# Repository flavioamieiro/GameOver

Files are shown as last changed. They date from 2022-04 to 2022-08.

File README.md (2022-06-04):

Hardware for Game Over project

[BaseBoard](BaseBoard/) contains the design files for the  main board, which
has an ESP32 and will be the base for the add-ons.

[BNO055Sensor](BNO055Sensor/) is the first add-on: basically a BNO055 sensor
from Adafruit used for motion detection.

[Keypad](Keypad/) is a keypad with six buttons and LEDs to be used as
an interface.

[BreakoutBoard](BreakoutBoard/) is a simple breakout board for easier
prototyping using the base board.

[AddonTemplate](AddonTemplate/) is a kicad template you can use as a base to
create new addon boards.

This source describes Open Hardware and is licensed under the CERN-OHL-S v2.
You may redistribute and modify this source and make products using it under
the terms of the [CERN-OHL-S v2](https://ohwr.org/cern_ohl_s_v2.txt).

Source location: https://github.com/flavioamieiro/GameOver

As per CERN-OHL-S v2 section 4, should You produce hardware based on this
source, You must where practicable maintain the Source Location visible on the
external case of the Gizmo or other products you make using this source.

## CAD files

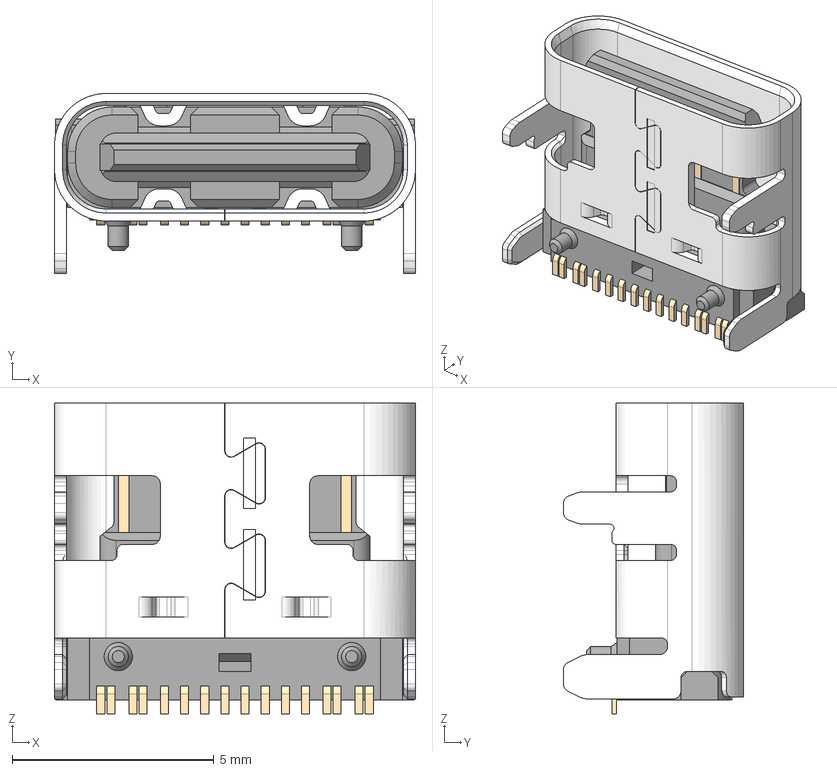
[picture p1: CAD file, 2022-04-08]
BNO055Sensor/3D-models/USB_C_Receptacle_USB_2_GTC_USB4105.step
8.94 x 4.46 x 7.70 mm
Move Face1
Imported1

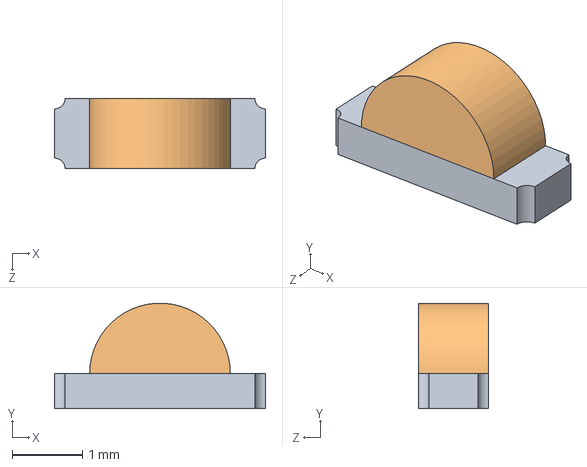
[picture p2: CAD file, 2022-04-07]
BNO055Sensor/3D-models/RGB_LED.step
3.00 x 1.50 x 1.00 mm

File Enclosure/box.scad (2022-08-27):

include <common.scad>

BOX_HAS_LOGO = true;

pcb_spacer_height = 5;
pcb_spacer_diameter = 6;
usb_support_offset = 5;

strap_cutout_size = [20, 100, 1.5];

button_hole_radius = 1;
button_center_height_from_board = 1.7;
button_1_from_left_edge = 18.8;
button_2_from_left_edge = 34.9;
button_3_from_left_edge = 40.5;

led_window_radius = 0.6;
led_window_thickness = 0.4;
led_from_left_edge = 25.3;
led_center_height_from_board = 0.5;

usb_height = 7;
usb_length = 13;
usb_z_padding = 1.5;
usb_center_from_pcb_bottom_edge = 24.65;


module main_box() {
	difference() {
		rounded_box(outer_size, radius=rounded_corner_radius);
		translate(inner_pocket_offset) rounded_box(inner_size, radius=rounded_corner_radius);
	}
}

module support_spacer() {
	inner_h = pcb_spacer_height;
	outer_d = pcb_spacer_diameter;
	outer_h = inner_h + wall_thickness;
	inner_offset_z = (outer_h - inner_h);
	cylinder(outer_h, d=outer_d);
}

module pcb_spacers() {
	translate(left_screw_pos) heat_set_insert_M2();
	translate([left_screw_pos.x+usb_support_offset, right_screw_pos.y, 0]) support_spacer();
	translate([right_screw_pos.x, left_screw_pos.y, 0]) support_spacer();
	translate(right_screw_pos) heat_set_insert_M2();
}

module strap_cutout() {
	translate([(outer_size.x / 2)-(strap_cutout_size.x/2), 0, wall_thickness]) cube(strap_cutout_size);
}

module led_window() {
	x = wall_thickness + wall_to_pcb_spacing + led_from_left_edge;
	y = outer_size.y - led_window_thickness;
	z = pcb_spacer_height + wall_thickness - led_center_height_from_board;
	cylinder_height = wall_thickness - led_window_thickness;
	translate([x, y, z]) rotate(a=90, v=[1, 0, 0]) cylinder(cylinder_height, r=led_window_radius);
}

module button_access(dist_from_left_pcb_edge) {
	x = wall_thickness + wall_to_pcb_spacing + dist_from_left_pcb_edge;
	y = outer_size.y;
	z = pcb_spacer_height + wall_thickness + pcb_size.z + button_center_height_from_board;
	translate([x, y, z]) rotate(a=90, v=[1, 0, 0])  cylinder(wall_thickness, r=button_hole_radius);
}

module button_accesses() {
	button_access(button_1_from_left_edge);
	button_access(button_2_from_left_edge);
	button_access(button_3_from_left_edge);
}

module usb_port_access() {
	radius = usb_height/2;
	center_y = wall_thickness + wall_to_pcb_spacing + usb_center_from_pcb_bottom_edge;
	y = center_y - (usb_length/2);
	z = wall_thickness + pcb_spacer_height - usb_height + usb_z_padding;
	translate([wall_thickness*2, y, z]) rotate(a=270, v=[0, 1, 0]) hull() {
		translate([radius, radius, 0]) cylinder(wall_thickness*2, r=radius);
		translate([radius, usb_length-radius, 0]) cylinder(wall_thickness*2, r=radius);
	}
}

module logo() {
	translate([outer_size.x-(wall_thickness/2), outer_size.y-(inner_size.y-wall_thickness), 0]) rotate([90, 0, 90]) scale([0.1, 0.1, 1]) linear_extrude(height=wall_thickness/2) import("logo.svg");
}

difference() {
	main_box();
	strap_cutout();
	button_accesses();
	led_window();
	usb_port_access();
	if (BOX_HAS_LOGO) {
		logo();
	}
}
pcb_spacers();

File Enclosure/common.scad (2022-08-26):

$fn=100;

rounded_corner_radius = 3;
wall_thickness = 2;
wall_to_pcb_spacing = 1;

inner_width = 50;
inner_depth = 35;
inner_height = 17;

pcb_size = [50, 35, 1.6];

right_side_padding = 15;

screw_center_from_pcb_edge = 3;
ffc_connector_from_right_pcb_edge = 5.5;


// Calculated variables
pcb_to_wall_padding = [1, 1, 1] * (2*wall_to_pcb_spacing);
inner_size = [inner_width + right_side_padding, inner_depth, inner_height] + pcb_to_wall_padding;
inner_pocket_offset = [1, 1, 1] * wall_thickness;

left_screw_pos = [wall_thickness + wall_to_pcb_spacing + screw_center_from_pcb_edge, wall_thickness + wall_to_pcb_spacing + screw_center_from_pcb_edge, 0];

right_screw_pos = [wall_thickness + wall_to_pcb_spacing + pcb_size.x - screw_center_from_pcb_edge, wall_thickness + wall_to_pcb_spacing + pcb_size.y - screw_center_from_pcb_edge, 0];

two_walls = (wall_thickness * 2);
outer_size = inner_size + [two_walls, two_walls, wall_thickness];


// Modules
module rounded_box(size = [1, 1, 1], radius=1) {
	if (size[0] == undef) {
		size = [size, size, size];
	}

	hull() {
		translate([radius, radius, 0]) cylinder(size.z, r=radius);
		translate([size.x-radius, radius, 0]) cylinder(size.z, r=radius);
		translate([radius, size.y-radius, 0]) cylinder(size.z, r=radius);
		translate([size.x-radius, size.y-radius, 0]) cylinder(size.z, r=radius);
	}
}

module heat_set_insert_M2() {
	inner_d = 3.2;
	inner_h = pcb_spacer_height;
	outer_d = pcb_spacer_diameter;
	outer_h = inner_h + wall_thickness;
	inner_offset_z = (outer_h - inner_h);
	difference() {
		cylinder(outer_h, d=outer_d);
		translate([0, 0, inner_offset_z]) cylinder(inner_h, d=inner_d);
	}
}

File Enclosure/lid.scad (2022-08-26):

include <common.scad>

LID_HAS_SCREW = false;
LID_HAS_LOGO = false;


lid_overhang = 5;
vertical_lid_wall_height = 1.5;
vertical_lid_wall_thickness = 1;

lid_outer_size = [outer_size.x, outer_size.y, wall_thickness*2];



module screw_hole() {
	inner_d = 3.2;
	inner_h = lid_outer_size.z;
	outer_d = 4.5;
	outer_h = inner_h/2;
	cylinder(inner_h, d=inner_d);
	translate([0, 0, outer_h]) cylinder(outer_h, d=outer_d);
}


module main_body() {
	opening_right_backoff = ((wall_to_pcb_spacing+wall_thickness)*2) + right_side_padding + ffc_connector_from_right_pcb_edge;
	opening_size = inner_size - [opening_right_backoff, lid_overhang, -100];
	translate([0, 0, vertical_lid_wall_height]) union() {
		difference() {
			rounded_box(lid_outer_size, radius=rounded_corner_radius);
			translate([lid_overhang, lid_overhang, 0]) rounded_box(opening_size, radius=rounded_corner_radius);
		};
	};
}


module vertical_walls() {
	out_size = lid_outer_size - [2*wall_thickness, 2*wall_thickness, -vertical_lid_wall_height];
	in_size = out_size - [2*vertical_lid_wall_thickness, 2*vertical_lid_wall_thickness, 0];
	translate([wall_thickness, wall_thickness, 0]) {
		difference() {
			rounded_box(out_size, radius=rounded_corner_radius);
			translate([vertical_lid_wall_thickness, vertical_lid_wall_thickness, 0]) rounded_box(in_size, radius=rounded_corner_radius);
		}
	}
}


module screw_opening() {
	z = vertical_lid_wall_height;
	translate([right_screw_pos.x, right_screw_pos.y, z]) screw_hole();
}


module logo() {
	translate([lid_outer_size.x, lid_outer_size.y-inner_size.y, lid_outer_size.z]) rotate([0, 0, 90]) scale([0.1, 0.1, 1]) linear_extrude(height=lid_outer_size.z/2) import("logo.svg");
}


difference() {
	union() {
		main_body();
		vertical_walls();
	}
	if (LID_HAS_SCREW) {
		screw_opening();
	}
	if (LID_HAS_LOGO) {
		logo();
	}
}

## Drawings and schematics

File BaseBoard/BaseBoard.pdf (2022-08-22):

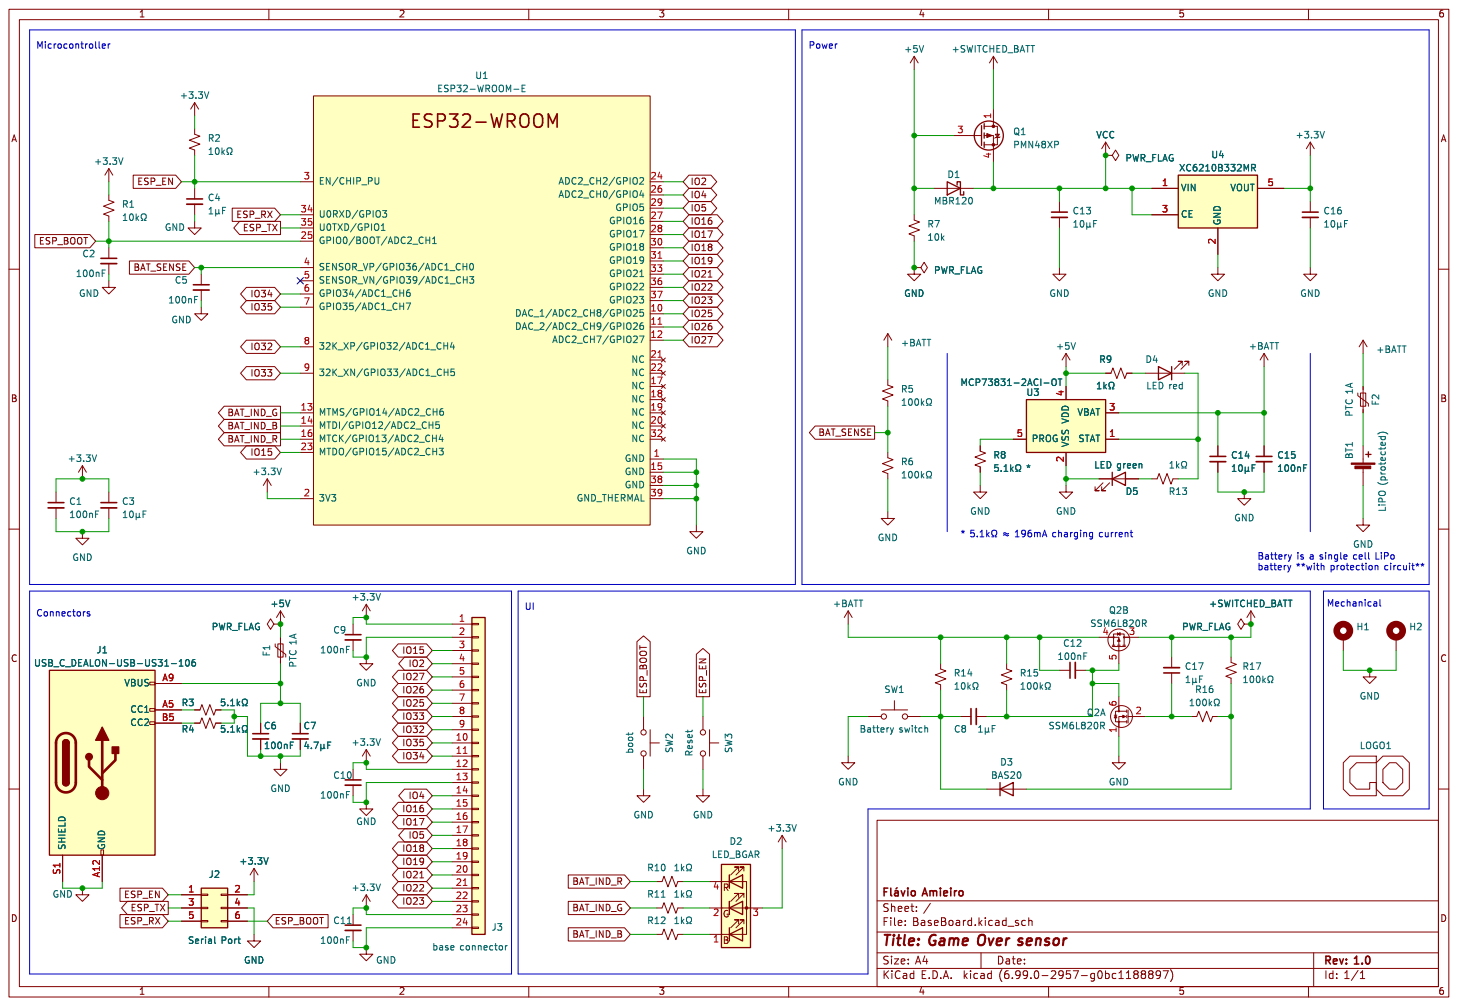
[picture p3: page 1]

þÿ10µF GND GND GND

battery **with protection circuit** Connectors

File: BaseBoard.kicad_sch Sheet: / þÿFlávio Amieiro C7

Id: 1/1 Title: Game Over sensor

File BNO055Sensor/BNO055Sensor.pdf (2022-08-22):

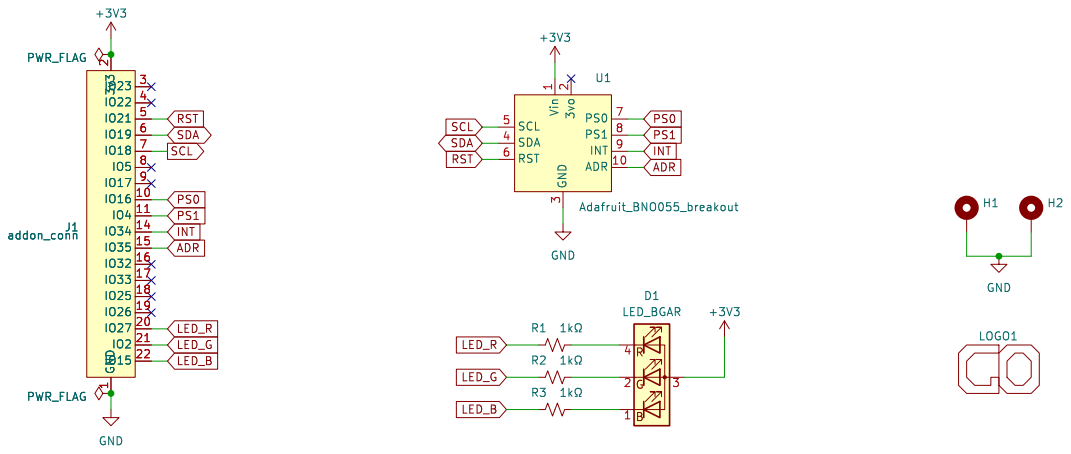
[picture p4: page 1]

Id: 1/1 Title: Game Over Sensor addon

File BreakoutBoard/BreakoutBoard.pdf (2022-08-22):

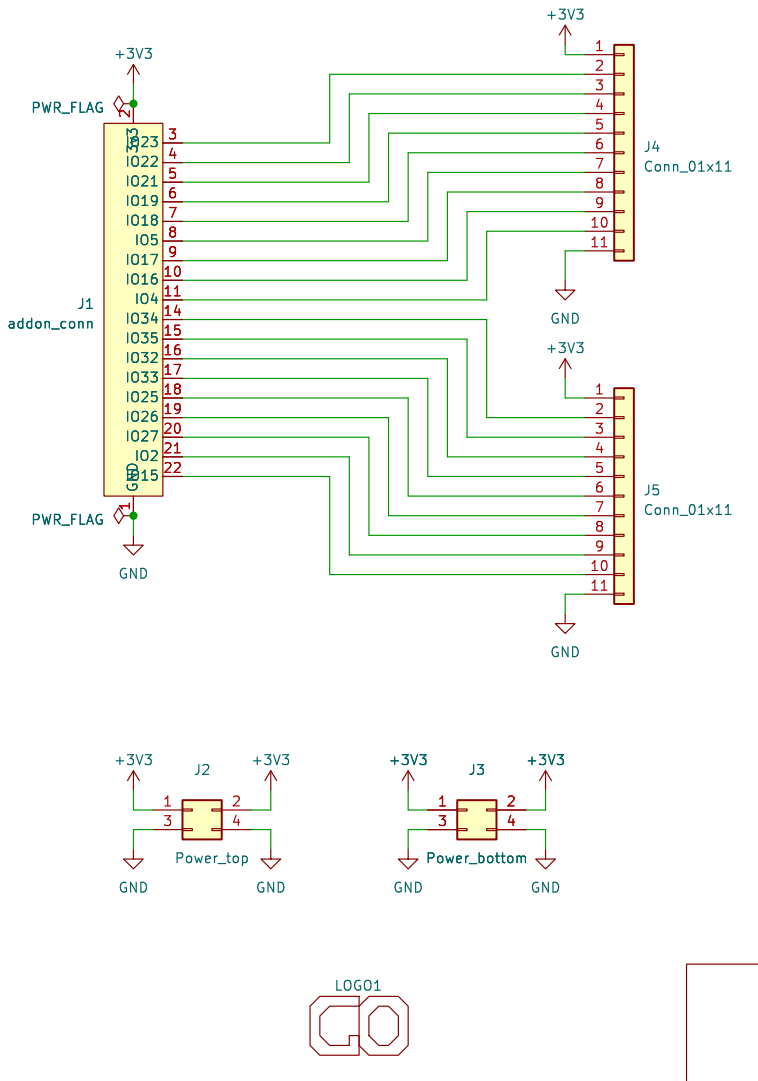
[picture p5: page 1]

Id: 1/1 Title: GameOver breakout board

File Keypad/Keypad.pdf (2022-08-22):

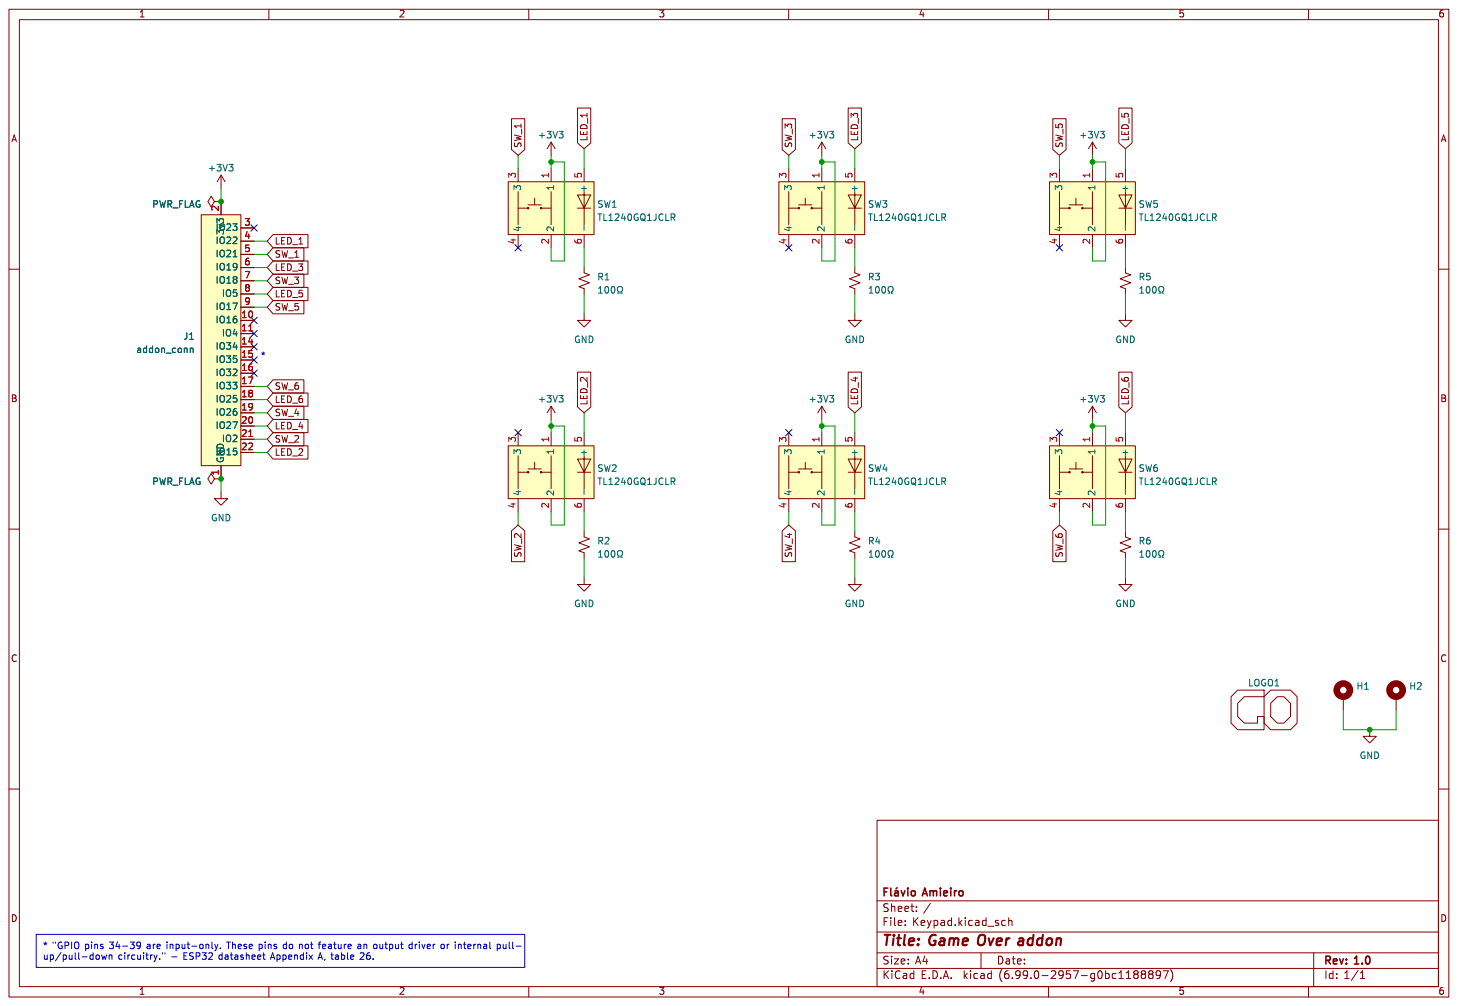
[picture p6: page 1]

Id: 1/1 Title: Game Over addon

* "GPIO pins 34-39 are input-only. These pins do not feature an output driver or internal pull-
up/pull-down circuitry." - ESP32 datasheet Appendix A, table 26.

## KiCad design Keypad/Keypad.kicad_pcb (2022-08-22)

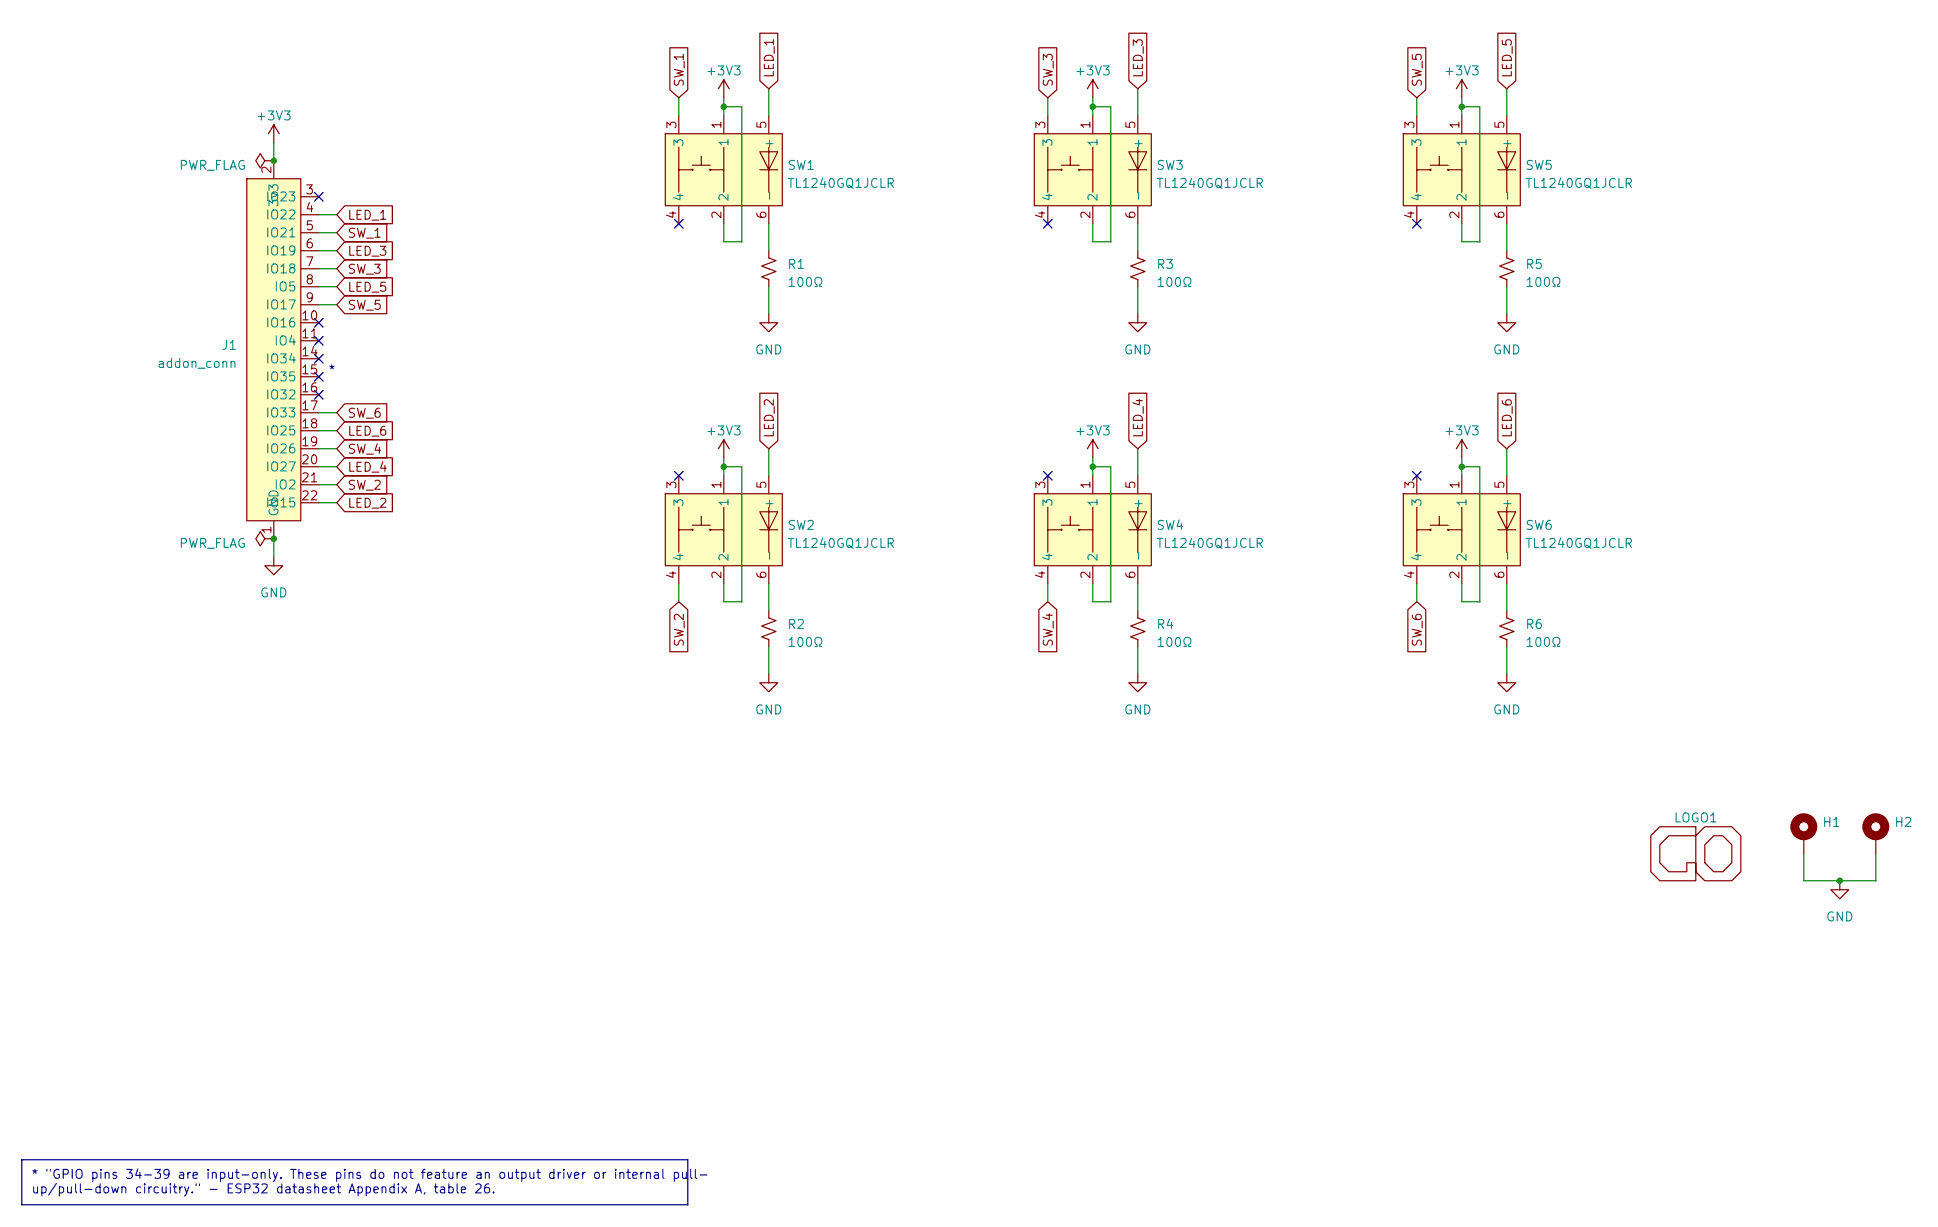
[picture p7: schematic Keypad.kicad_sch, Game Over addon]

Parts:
H1, H2: MountingHole_2.2mm_M2_Pad_Via
J1: addon_conn; Addon_conn_TXGA_FFC05036-24SBD113W5M_1x24_P0.50mm_Horizontal
LOGO1: GameOver_logo; logo_fcu
R1, R2, R3, R4, R5, R6: 100Ω; R_0805_2012Metric_Pad1.20x1.40mm_HandSolder
SW1, SW2, SW3, SW4, SW5, SW6: TL1240GQ1JCLR

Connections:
+3V3: J1.2 (3v3), J1.13 (3v3), J1.24 (3v3), SW1.1, SW1.2, SW2.1, SW2.2, SW3.1, SW3.2, SW4.1, SW4.2, SW5.1, SW5.2, SW6.1, SW6.2
GND: H1.1, H2.1, J1.1 (GND), J1.12 (GND), J1.23 (GND), R1.2, R2.2, R3.2, R4.2, R5.2, R6.2
LED_1: J1.4 (IO22), SW1.5 (+)
LED_2: J1.22 (IO15), SW2.5 (+)
LED_3: J1.6 (IO19), SW3.5 (+)
LED_4: J1.20 (IO27), SW4.5 (+)
LED_5: J1.8 (IO18), SW5.5 (+)
LED_6: J1.18 (IO25), SW6.5 (+)
unnamed: R1.1, SW1.6 (-)
unnamed: R2.1, SW2.6 (-)
unnamed: R3.1, SW3.6 (-)
unnamed: R4.1, SW4.6 (-)
unnamed: R5.1, SW5.6 (-)
unnamed: R6.1, SW6.6 (-)
SW_1: J1.5 (IO21), SW1.3
SW_2: J1.21 (IO2), SW2.4
SW_3: J1.7 (IO5), SW3.3
SW_4: J1.19 (IO26), SW4.4
SW_5: J1.9 (IO17), SW5.3
SW_6: J1.17 (IO33), SW6.4

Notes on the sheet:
* "GPIO pins 34-39 are input-only. These pins do not feature an output driver or internal pull- up/pull-down circuitry." - ESP32 datasheet Appendix A, table 26.

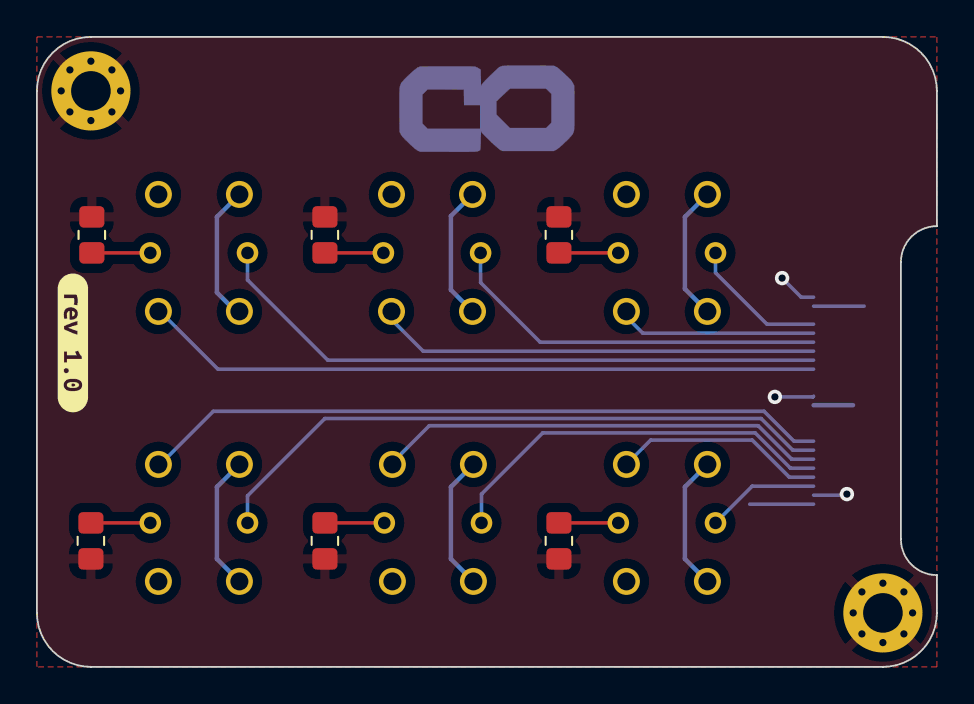
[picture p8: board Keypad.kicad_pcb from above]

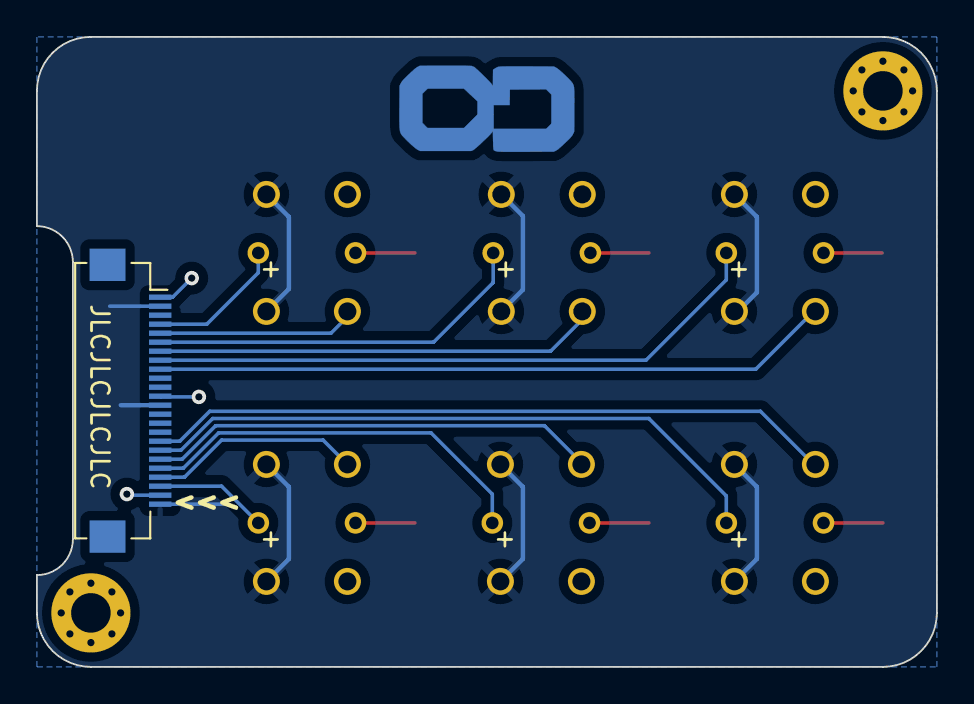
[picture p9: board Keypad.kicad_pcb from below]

Board: 2 copper layers, 50.0 x 35.0 mm, 17 parts (8 on the bottom side), 20 nets.

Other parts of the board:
kibuzzard-63029D1F: G***; kibuzzard-63029D1F

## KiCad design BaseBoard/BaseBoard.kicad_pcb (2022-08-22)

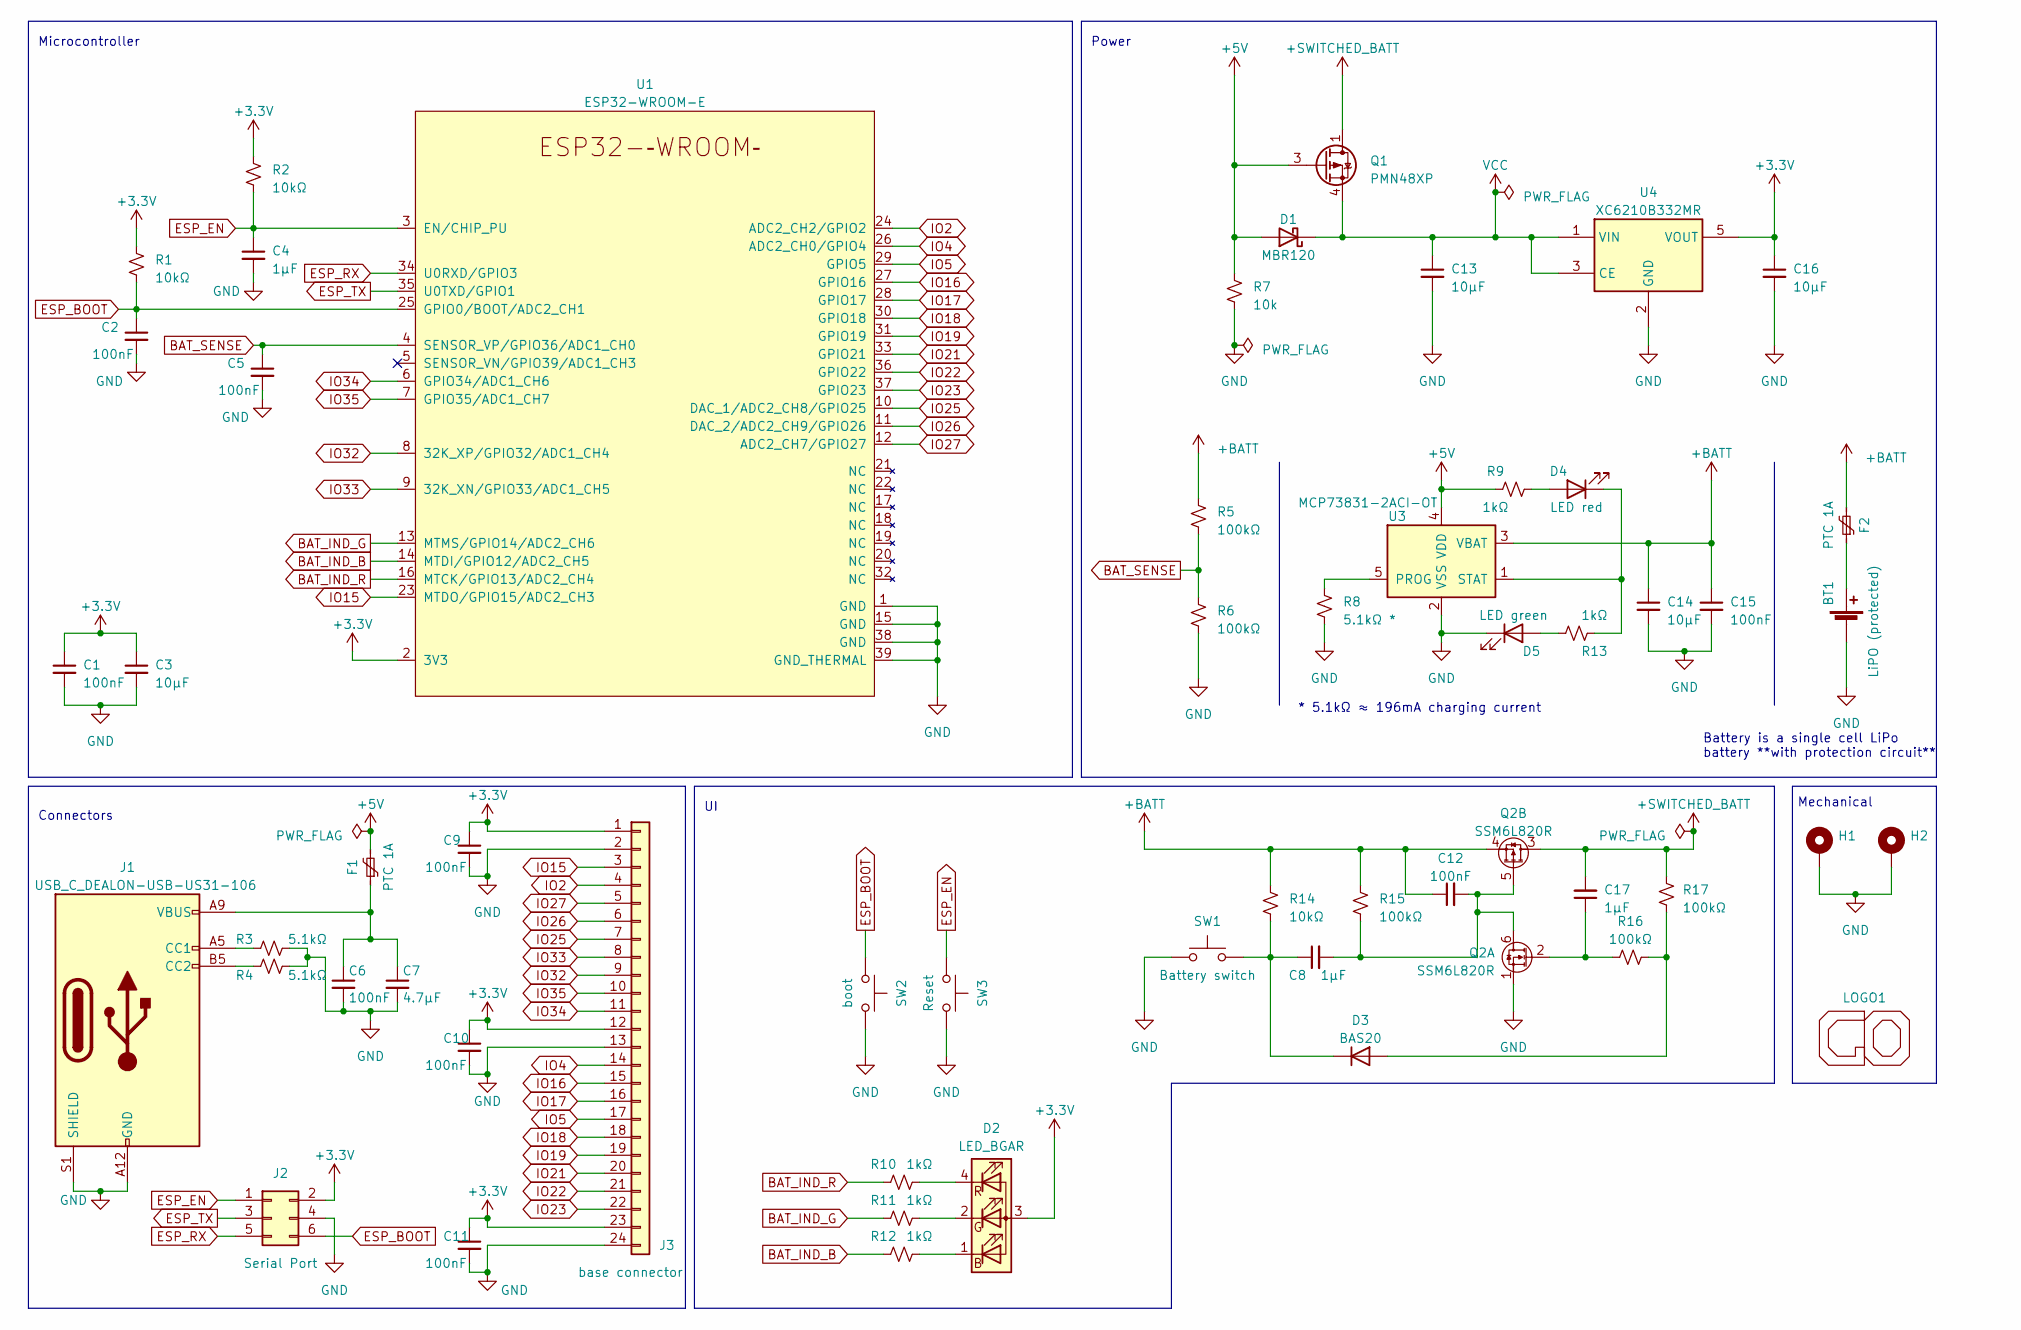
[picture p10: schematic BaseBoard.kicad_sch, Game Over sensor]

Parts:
BT1: LiPO (protected); JST_PH_S2B-PH-SM4-TB_1x02-1MP_P2.00mm_Horizontal
C1, C2, C5, C6, C9, C10, C11, C12, C15: 100nF; C_0805_2012Metric_Pad1.18x1.45mm_HandSolder
C3, C13, C14, C16: 10µF; C_0805_2012Metric_Pad1.18x1.45mm_HandSolder
C4, C8, C17: 1µF; C_0805_2012Metric_Pad1.18x1.45mm_HandSolder
C7: 4.7µF; C_0805_2012Metric_Pad1.18x1.45mm_HandSolder
D1: MBR120; D_SOD-123
D2: LED_BGAR; Hongzhi_Forest_HS-1204-RGB
D3: BAS20; SOT-23
D4: LED red; LED_0603_1608Metric
D5: LED green; LED_0603_1608Metric
F1, F2: PTC 1A; Belfuse_0ZCJ
H1, H2: MountingHole_2.2mm_M2_Pad_Via
J1: USB_C_DEALON-USB-US31-106; DEALON_USB-US31-106
J2: Serial Port; Tag-Connect_TC2030-IDC-FP_2x03_P1.27mm_Vertical
J3: base connector; Base_conn_TXGA_FFC05036-24SBD113W5M_1x24_P0.50mm_Horizontal
LOGO1: GameOver_logo; logo_fsilk
Q1: PMN48XP; TSOP-6_1.65x3.05mm_P0.95mm
Q2: SSM6L820R; TSOP6F
R1, R2, R14: 10kΩ; R_0805_2012Metric_Pad1.20x1.40mm_HandSolder
R3, R4: 5.1kΩ; R_0805_2012Metric_Pad1.20x1.40mm_HandSolder
R5, R6, R15, R16, R17: 100kΩ; R_0805_2012Metric_Pad1.20x1.40mm_HandSolder
R7: 10k; R_0805_2012Metric_Pad1.20x1.40mm_HandSolder
R8: 5.1kΩ *; R_0805_2012Metric_Pad1.20x1.40mm_HandSolder
R9, R10, R11, R12, R13: 1kΩ; R_0805_2012Metric_Pad1.20x1.40mm_HandSolder
SW1: Battery switch; SW_Tactile_SPST_SOFNG_TS-1814
SW2: boot; SW_Tactile_SPST_SOFNG_TS-1814
SW3: Reset; SW_Tactile_SPST_SOFNG_TS-1814
U1: ESP32-WROOM-E; ESP32-WROOM-32E
U3: MCP73831-2ACI-OT; SOT-23-5
U4: XC6210B332MR; SOT-23-5

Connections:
+3V3: C1.1, C3.1, C9.1, C10.1, C11.1, C16.1, D2.3 (A), J2.2, J3.1, J3.12, J3.23, R1.1, R2.1, U1.2 (3V3), U4.5 (VOUT)
+5V: D1.2 (A), F1.2, Q1.3 (G), R7.1, R9.2, U3.4 (VDD)
+BATT: C12.1, C14.1, C15.1, F2.2, Q2.4 (S), R5.1, R14.1, R15.1, U3.3 (VBAT)
+SWITCHED_BATT: C17.2, Q1.1 (D), Q1.2 (D), Q1.5 (D), Q1.6 (D), Q2.3 (D), R17.2
BAT_IND_B: R12.1, U1.14 (MTDI/GPIO12/ADC2_CH5)
BAT_IND_G: R11.1, U1.13 (MTMS/GPIO14/ADC2_CH6)
BAT_IND_R: R10.1, U1.16 (MTCK/GPIO13/ADC2_CH4)
BAT_SENSE: C5.1, R5.2, R6.1, U1.4 (SENSOR_VP/GPIO36/ADC1_CH0)
ESP_BOOT: C2.1, J2.6, R1.2, SW2.1, U1.25 (GPIO0/BOOT/ADC2_CH1)
ESP_EN: C4.1, J2.1, R2.2, SW3.1, U1.3 (EN/CHIP_PU)
ESP_RX: J2.5, U1.34 (U0RXD/GPIO3)
ESP_TX: J2.3, U1.35 (U0TXD/GPIO1)
GND: BT1.2 (-), C1.2, C2.2, C3.2, C4.2, C5.2, C6.2, C7.2, C9.2, C10.2, C11.2, C13.2, C14.2, C15.2, C16.2, D5.1 (K), H1.1, H2.1, J1.A12 (GND), J1.B12 (GND), J1.S1 (SHIELD), J2.4, J3.2, J3.13, J3.24, Q2.1 (S), R3.2, R4.2, R6.2, R7.2, R8.2, SW1.1, SW2.2, SW3.2, U1.1 (GND), U1.15 (GND), U1.38 (GND), U1.39 (GND_THERMAL), U3.2 (VSS), U4.2 (GND)
IO2: J3.4, U1.24 (ADC2_CH2/GPIO2)
IO4: J3.14, U1.26 (ADC2_CH0/GPIO4)
IO5: J3.17, U1.29 (GPIO5)
IO15: J3.3, U1.23 (MTDO/GPIO15/ADC2_CH3)
IO16: J3.15, U1.27 (GPIO16)
IO17: J3.16, U1.28 (GPIO17)
IO18: J3.18, U1.30 (GPIO18)
IO19: J3.19, U1.31 (GPIO19)
IO21: J3.20, U1.33 (GPIO21)
IO22: J3.21, U1.36 (GPIO22)
IO23: J3.22, U1.37 (GPIO23)
IO25: J3.7, U1.10 (DAC_1/ADC2_CH8/GPIO25)
IO26: J3.6, U1.11 (DAC_2/ADC2_CH9/GPIO26)
IO27: J3.5, U1.12 (ADC2_CH7/GPIO27)
IO32: J3.9, U1.8 (32K_XP/GPIO32/ADC1_CH4)
IO33: J3.8, U1.9 (32K_XN/GPIO33/ADC1_CH5)
IO34: J3.11, U1.6 (GPIO34/ADC1_CH6)
IO35: J3.10, U1.7 (GPIO35/ADC1_CH7)
unnamed: BT1.1 (+), F2.1
unnamed: D2.1 (BK), R12.2
unnamed: D2.2 (GK), R11.2
unnamed: D2.4 (RK), R10.2
unnamed: D3.1 (A), R16.2, R17.1
unnamed: C8.1, D3.3 (K), R14.2, SW1.2
unnamed: D4.2 (A), R9.1
unnamed: D4.1 (K), R13.2, U3.1 (STAT)
unnamed: D5.2 (A), R13.1
unnamed: J1.A5 (CC1), R3.1
unnamed: J1.B5 (CC2), R4.1
unnamed: C6.1, C7.1, F1.1, J1.A9 (VBUS), J1.B9 (VBUS)
unnamed: C8.2, C12.2, Q2.5 (G), Q2.6 (D), R15.2
unnamed: C17.1, Q2.2 (G), R16.1
unnamed: R8.1, U3.5 (PROG)
VCC: C13.1, D1.1 (K), Q1.4 (S), U4.1 (VIN), U4.3 (CE)

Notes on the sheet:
Microcontroller
Connectors
Battery is a single cell LiPo battery **with protection circuit**
Power
* 5.1kΩ ≈ 196mA charging current
Mechanical

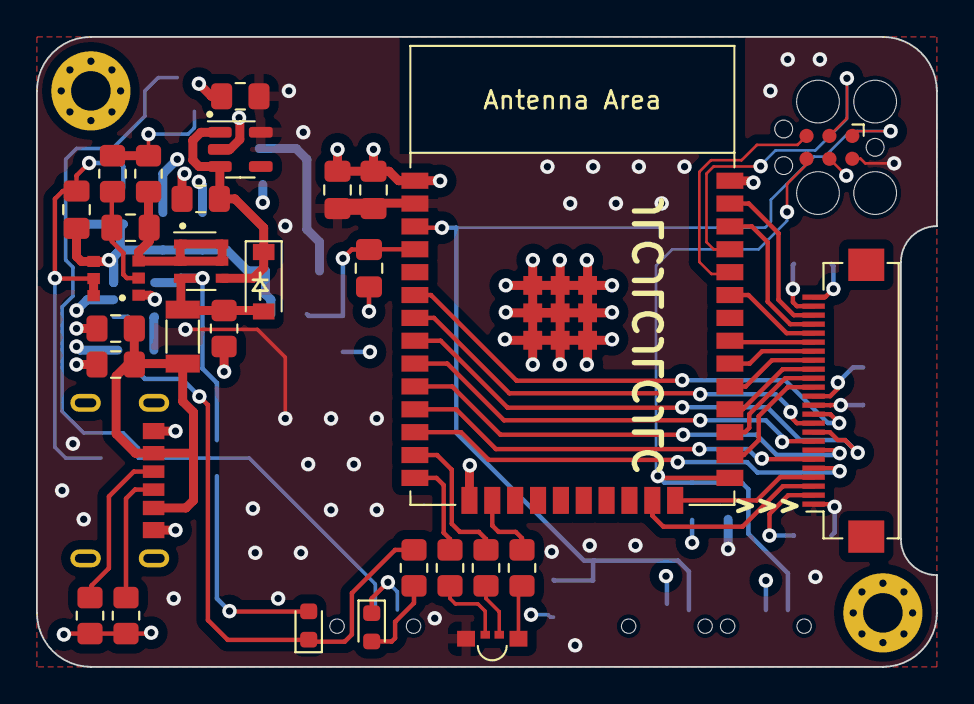
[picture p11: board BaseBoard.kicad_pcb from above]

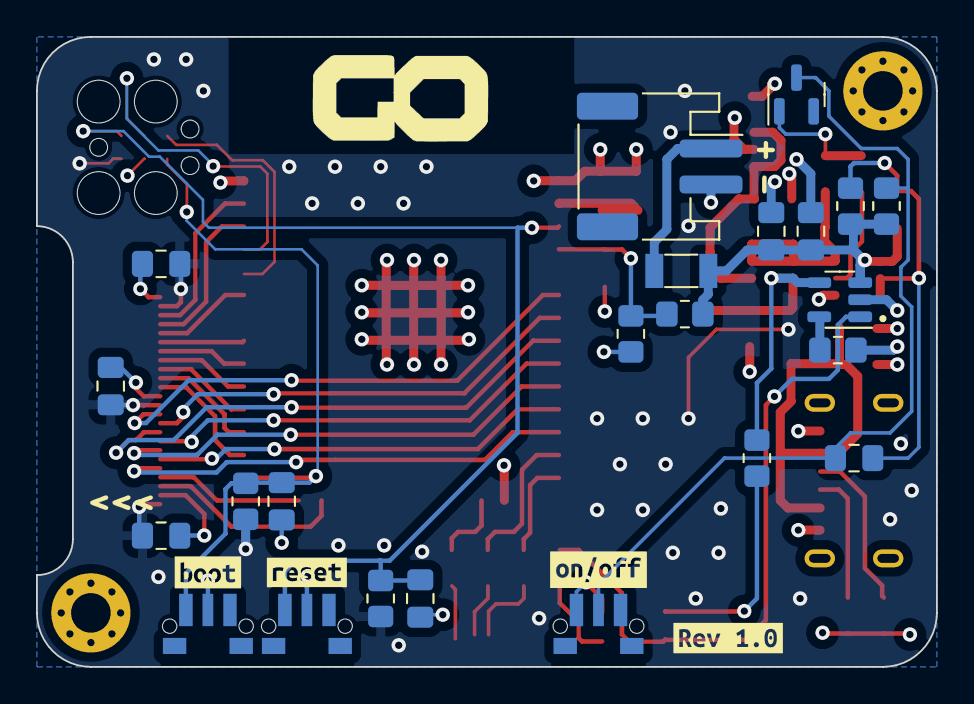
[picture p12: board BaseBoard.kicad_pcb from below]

Board: 4 copper layers, 50.0 x 35.0 mm, 60 parts (28 on the bottom side), 47 nets.

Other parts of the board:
kibuzzard-6253FE4C: G***; kibuzzard-6253FE4C
kibuzzard-6253FE42: G***; kibuzzard-6253FE42
kibuzzard-63029C06: G***; kibuzzard-63029C06
kibuzzard-63029CBF: G***; kibuzzard-63029CBF

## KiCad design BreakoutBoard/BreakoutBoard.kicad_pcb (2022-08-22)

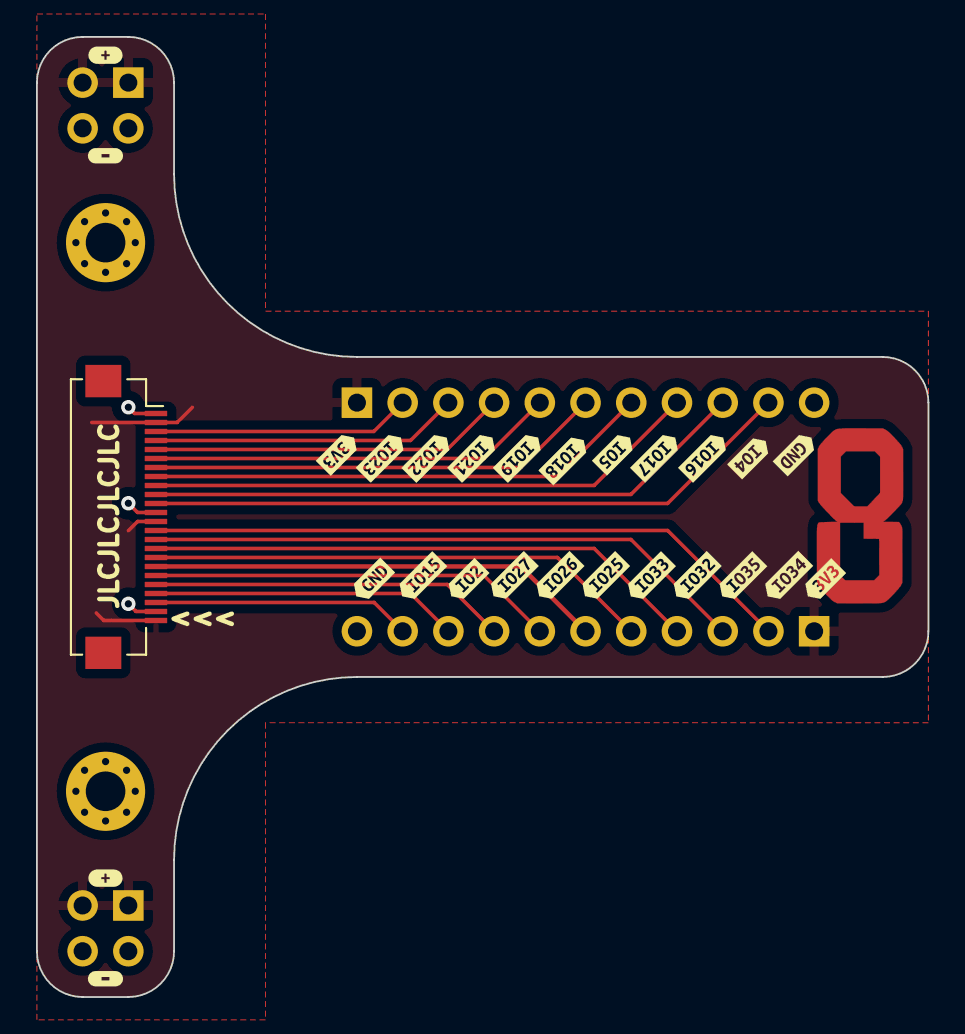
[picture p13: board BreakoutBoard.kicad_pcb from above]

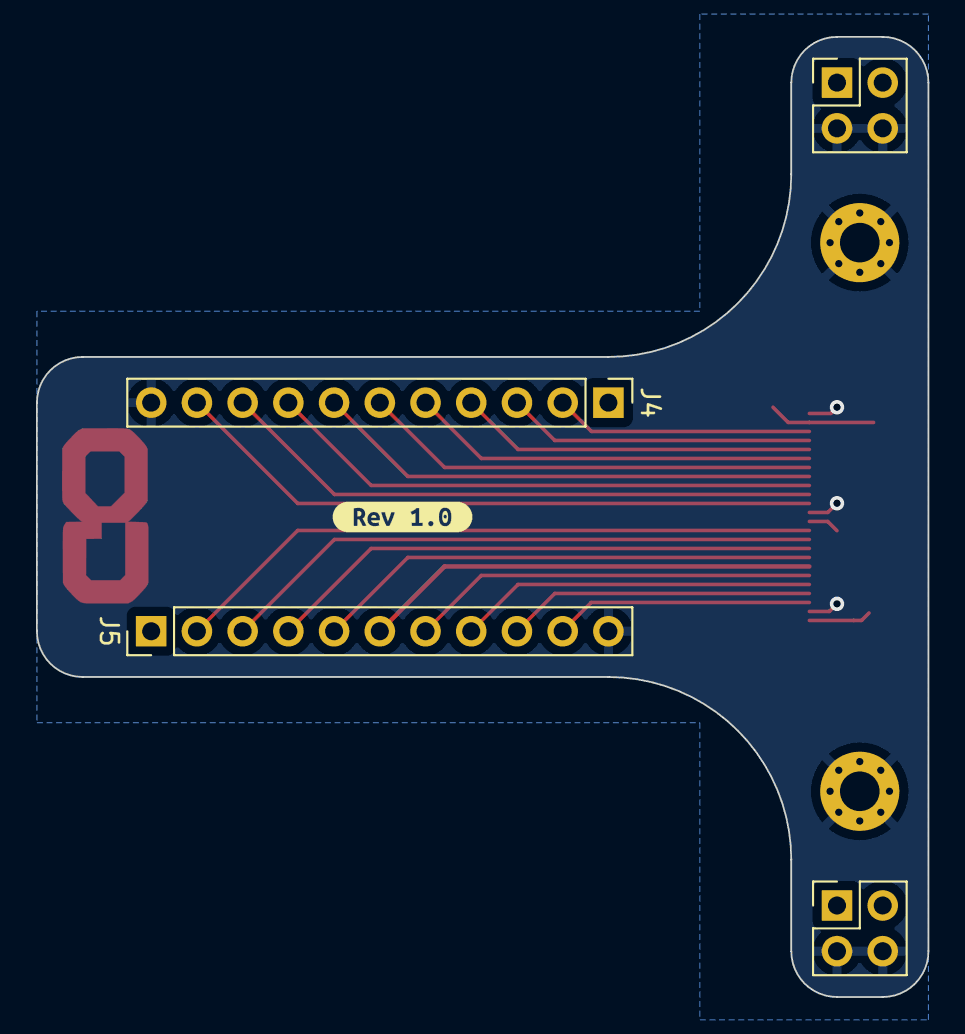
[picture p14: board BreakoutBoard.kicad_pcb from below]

Board: 2 copper layers, 49.5 x 53.3 mm, 35 parts (5 on the bottom side), 20 nets.

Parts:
H1, H2: MountingHole_2.2mm_M2_Pad_Via
J1: addon_conn; Addon_conn_TXGA_FFC05036-24SBD113W5M_1x24_P0.50mm_Horizontal
J2: Power_top; PinHeader_2x02_P2.54mm_Vertical
J3: Power_bottom; PinHeader_2x02_P2.54mm_Vertical
J4, J5: Conn_01x11; PinHeader_1x11_P2.54mm_Vertical
LOGO1: GameOver_logo; logo_fcu
kibuzzard-62829C43: G***; kibuzzard-62829C43
kibuzzard-62829C54: G***; kibuzzard-62829C54
kibuzzard-62829CE0: G***; kibuzzard-62829CE0
kibuzzard-62829D2F: G***; kibuzzard-62829D2F
kibuzzard-62829D15: G***; kibuzzard-62829D15
kibuzzard-62829D34: G***; kibuzzard-62829D34
kibuzzard-63029CFF: G***; kibuzzard-63029CFF
kibuzzard-625944D4: G***; kibuzzard-625944D4
kibuzzard-625944DF: G***; kibuzzard-625944DF
kibuzzard-625944E4: G***; kibuzzard-625944E4
kibuzzard-625944EE: G***; kibuzzard-625944EE
kibuzzard-625944F4: G***; kibuzzard-625944F4
kibuzzard-625944FA: G***; kibuzzard-625944FA
kibuzzard-625944FF: G***; kibuzzard-625944FF
kibuzzard-6259425C, kibuzzard-6259425C#2: G***; kibuzzard-6259425C
kibuzzard-6259452C: G***; kibuzzard-6259452C
kibuzzard-6259453A: G***; kibuzzard-6259453A
kibuzzard-6259453E: G***; kibuzzard-6259453E
kibuzzard-62594249, kibuzzard-62594249#2: G***; kibuzzard-62594249
kibuzzard-62594504: G***; kibuzzard-62594504
kibuzzard-62594508: G***; kibuzzard-62594508
kibuzzard-62594532: G***; kibuzzard-62594532
kibuzzard-62594542: G***; kibuzzard-62594542
kibuzzard-62594546: G***; kibuzzard-62594546
kibuzzard-62594559: G***; kibuzzard-62594559

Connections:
+3V3: J1.2 (3v3), J1.13 (3v3), J1.24 (3v3), J2.1, J2.2, J3.1, J3.2, J4.1, J5.1
GND: H1.1, H2.1, J1.1 (GND), J1.12 (GND), J1.23 (GND), J2.3, J2.4, J3.3, J3.4, J4.11, J5.11
unnamed: J1.21 (IO2), J5.9
unnamed: J1.11 (IO4), J4.10
unnamed: J1.8 (IO5), J4.7
unnamed: J1.22 (IO15), J5.10
unnamed: J1.10 (IO16), J4.9
unnamed: J1.9 (IO17), J4.8
unnamed: J1.7 (IO18), J4.6
unnamed: J1.6 (IO19), J4.5
unnamed: J1.5 (IO21), J4.4
unnamed: J1.4 (IO22), J4.3
unnamed: J1.3 (IO23), J4.2
unnamed: J1.18 (IO25), J5.6
unnamed: J1.19 (IO26), J5.7
unnamed: J1.20 (IO27), J5.8
unnamed: J1.16 (IO32), J5.4
unnamed: J1.17 (IO33), J5.5
unnamed: J1.14 (IO34), J5.2
unnamed: J1.15 (IO35), J5.3

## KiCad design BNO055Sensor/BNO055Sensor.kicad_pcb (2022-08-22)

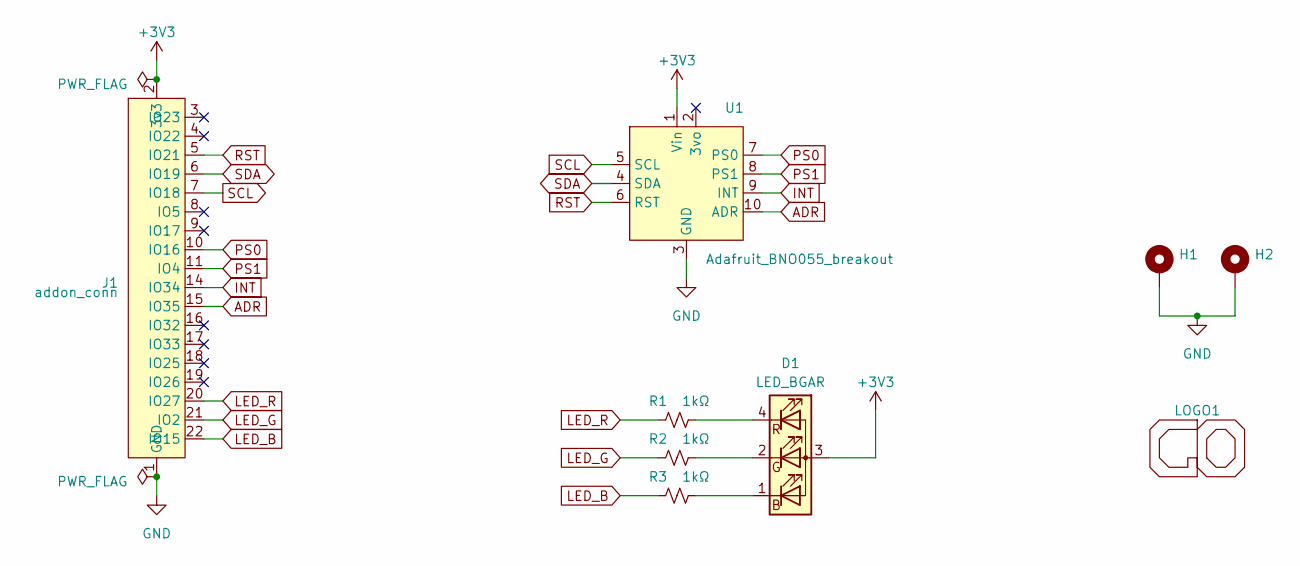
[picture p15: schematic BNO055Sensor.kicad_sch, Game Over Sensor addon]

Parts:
D1: LED_BGAR; Hongzhi_Forest_HS-1204-RGB
H1, H2: MountingHole_2.2mm_M2_Pad_Via
J1: addon_conn; Addon_conn_TXGA_FFC05036-24SBD113W5M_1x24_P0.50mm_Horizontal
LOGO1: GameOver_logo; logo_fcu
R1, R2, R3: 1kΩ; R_0805_2012Metric_Pad1.20x1.40mm_HandSolder
U1: Adafruit_BNO055_breakout

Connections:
+3V3: D1.3 (A), J1.2 (3v3), J1.13 (3v3), J1.24 (3v3), U1.1 (Vin)
ADR: J1.15 (IO35), U1.10 (ADR)
GND: H1.1, H2.1, J1.1 (GND), J1.12 (GND), J1.23 (GND), U1.3 (GND)
INT: J1.14 (IO34), U1.9 (INT)
LED_B: J1.22 (IO15), R3.1
LED_G: J1.21 (IO2), R2.1
LED_R: J1.20 (IO27), R1.1
unnamed: D1.1 (BK), R3.2
unnamed: D1.2 (GK), R2.2
unnamed: D1.4 (RK), R1.2
PS0: J1.10 (IO16), U1.7 (PS0)
PS1: J1.11 (IO4), U1.8 (PS1)
RST: J1.5 (IO21), U1.6 (RST)
SCL: J1.7 (IO18), U1.5 (SCL)
SDA: J1.6 (IO19), U1.4 (SDA)

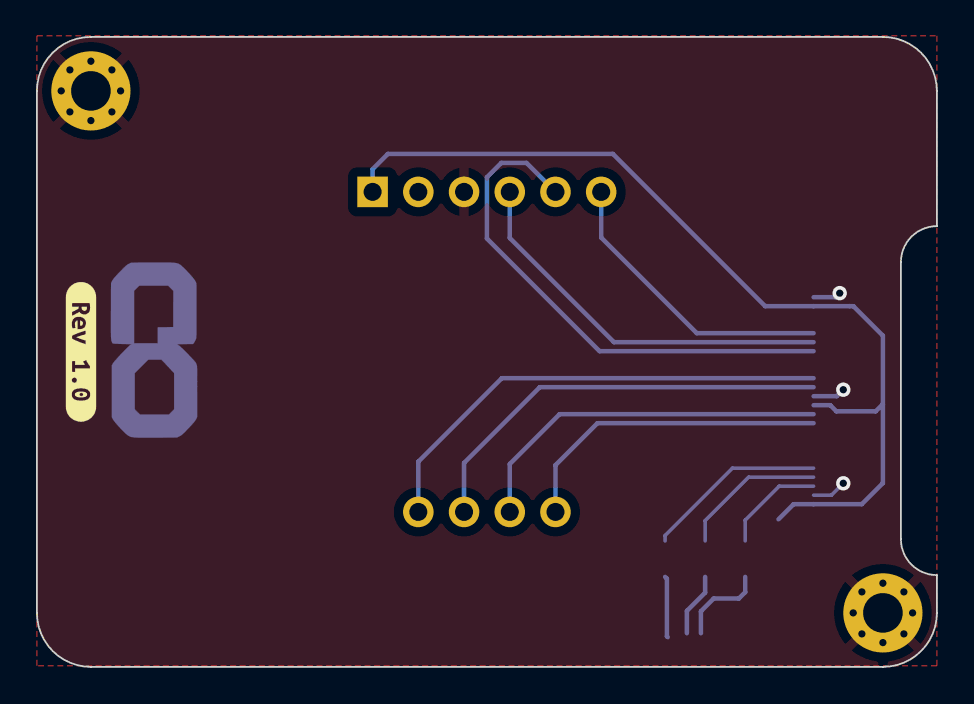
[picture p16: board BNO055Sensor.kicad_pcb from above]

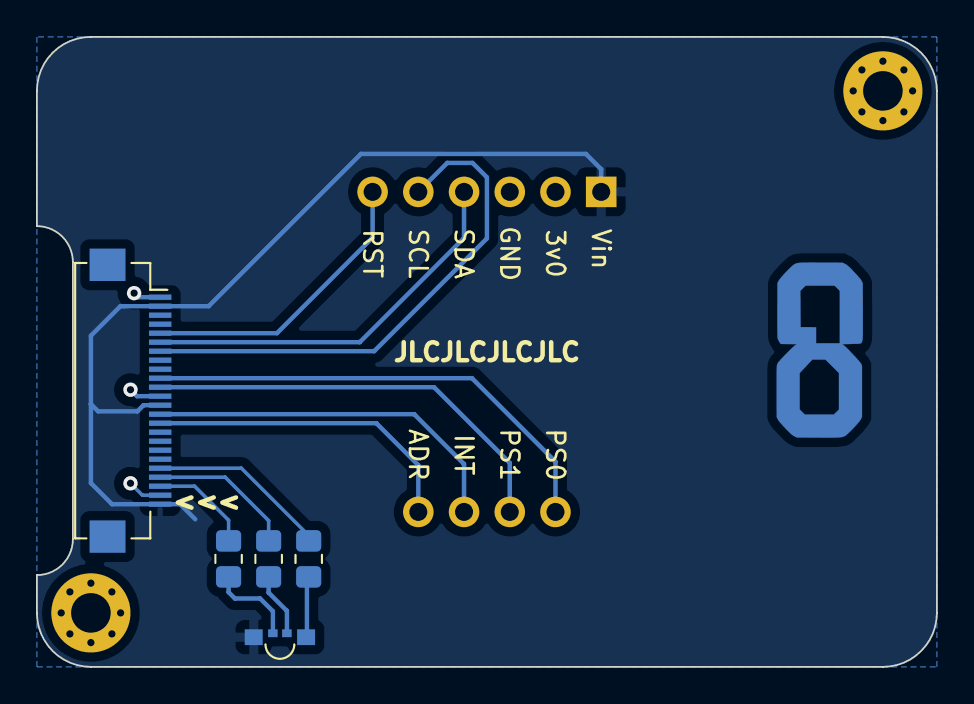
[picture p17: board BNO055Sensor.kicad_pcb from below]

Board: 2 copper layers, 50.0 x 35.0 mm, 10 parts (7 on the bottom side), 15 nets.

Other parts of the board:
kibuzzard-63029CE8: G***; kibuzzard-63029CE8

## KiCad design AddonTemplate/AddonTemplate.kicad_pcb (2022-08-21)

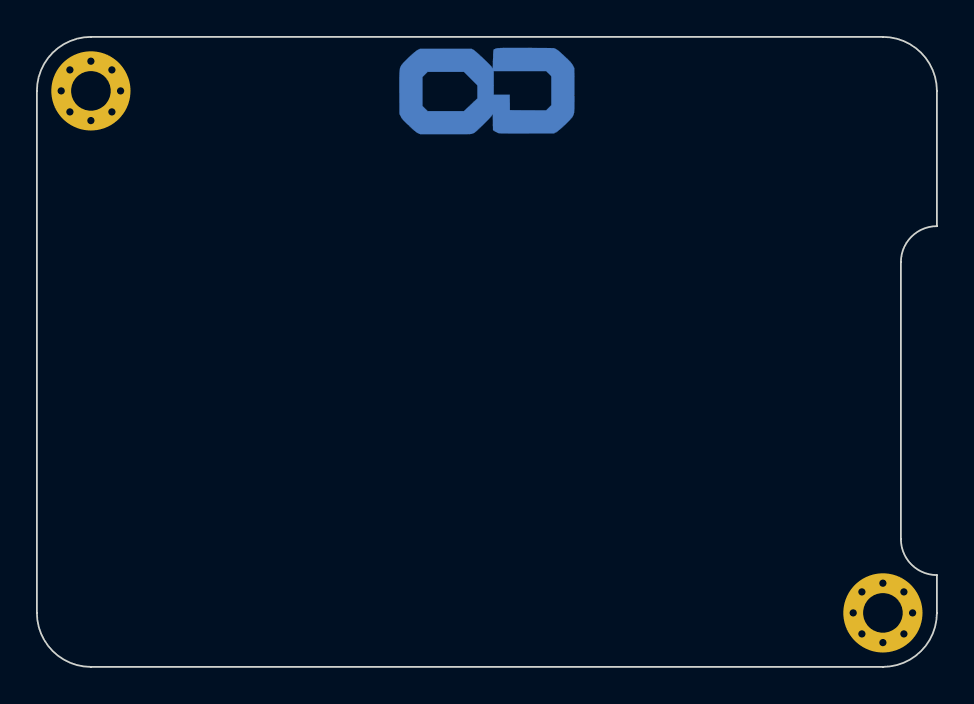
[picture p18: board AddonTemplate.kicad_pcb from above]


Board: 2 copper layers, 50.0 x 35.0 mm, 4 parts (2 on the bottom side), 2 nets, no tracks yet.

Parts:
H1, H2: MountingHole_2.2mm_M2_Pad_Via
J1: locked; Addon_conn_TXGA_FFC05036-24SBD113W5M_1x24_P0.50mm_Horizontal
LOGO1: GameOver_logo; logo_fcu

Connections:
+3V3: J1.2 (3v3), J1.13 (3v3), J1.24 (3v3)
GND: H1.1, H2.1, J1.1 (GND), J1.12 (GND), J1.23 (GND)

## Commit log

2022-03-03 Initial draft of a schematic for the sensor
    This uses XC6210B332MR as an LDO (replacing the usual AP2112K-3.3).
    Other ICs that we still don't have a replacement for have placeholders
    for now.
    We decided that the sensors will be programmed through an external
    USB to serial converter to save cost and space.
    [GameOverSensor.kicad_pcb, GameOverSensor.kicad_sch]
2022-03-04 Changes Serial Port connector to match esp-prog
    Both esp-prog and the tag connect cable use even/odd numbering for the
    two row connector.
    [GameOverSensor.kicad_sch]
2022-03-04 Adds battery charging circuit with an MCP73831
    The battery will be 400mA, which means we should use 200mA to charge the
    battery. This would mean a 5kΩ prog resistor. A 5.1kΩ resistor was
    chosen instead to simplify the BOM since we'll already use some of those
    in the USB configuration. This means a charging current of approximately
    196mA.
    [GameOverSensor.kicad_sch]
2022-03-04 Uses battery protection circuit around a BQ29703
    This IC has a over current during discharge threshold voltage of 0.160V.
    Using the DMG9926UDM MOSFETs, which have a Rds(on) of 0.032A each
    (0.064A in total), we would have a cutoff current of 2.5A. If we need
    this to be lower, we need to add a resistor in series with the MOSFETs
    to increase the voltage difference between VSS and V- in case of
    overcurrent.
    [GameOverSensor.kicad_sch]
2022-03-09 Removes on board battery protection circuit
    We decided we will only use battery packs that include their own
    protection mechanism, so we don't need to do it onboard also.
    We still kept the fuse as an extra protection for overcurrent.
    [GameOverSensor.kicad_sch]
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2022-03-09 Adds BON055 module symbol
    We will use the Adafruit BON055 breakout board as we couldn't source the
    BNO055 anywhere. This commit includes the schematic symbol but we still
    need to make the footprint to be included in the PCB.
    [GameOverSensor.kicad_sch]
2022-03-10 Adds voltage divider to sense battery level
    I decided to go with a simple voltage divider instead of a more complex
    circuit that could be turned off because with two 100k resistors this
    should mean a 21µA current when the battery is full (at 4.2V). This
    seems like a good tradeoff to have a simpler circuit/BOM and layout
    (since space is important here). Using two 100k might make the ADC a bit
    noisy here, but this should be enough to have a good idea of the battery
    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
    [GameOverSensor.kicad_sch]
2022-03-10 Adds LEDs to indicate battery level
    I used RGB LEDs instead of 3 different LEDs for no specific reason, that
    should be easy to change later if we prefer.
    1K resistors were chosen to have dim LEDs on purpose, this value can be
    adjusted to whatever makes sense later.
    [GameOverSensor.kicad_sch]
2022-03-10 Fixes pin directions and organizes the schematics a bit better
    [GameOverSensor.kicad_sch]
2022-03-10 Adds circuit to select device ID onboard
    We use a 4021 parallel to serial shift register to read the 8 bits of
    the ID selected on DIP switches with only 3 pins on the microcontroller.
    This comes at some cost in terms of BOM and PCB space, but we're already
    running short on pins on the µC.
    [GameOverSensor.kicad_sch]
2022-03-11 Pulls DIP switches down instead of up
    We want the value to be 0 when the switch is open, 1 when it's closed.
    [GameOverSensor.kicad_sch]
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2022-03-14 Removes IMU
    This PCB will be the base, on which we will connect other PCBs that add
    functionality to it. The IMU will be on it's own PCB, with it's own LED.
    The keypad will be a third PCB with the buttons and LEDs. The base and
    the add on PCB will be connected by a FFC connector that breaks out the
    the GPIO pins we're not using on the base.
    [GameOverSensor.kicad_sch]
2022-03-14 Renames project to GameOverBase
    The new base+addon approach means this is not the sensor anymore.
    [GameOverBase.kicad_pcb, GameOverBase.kicad_sch]
2022-03-14 Adds Boot button
    This can be used while programming the ESP32 and also as a general
    purpose button on IO0 after the intial bootstrap is done.
    [GameOverBase.kicad_sch]
2022-03-14 First draft for the board to board connector
    This is a bad layout, but it breaks out the pins we have left. They will
    be moved around still.
    [GameOverBase.kicad_sch]
2022-03-14 Switches to using espressif's official symbol for the ESP32 module
    Symbols are available in https://github.com/espressif/kicad-libraries
    This is more reliable, specially because kicad's official library
    doesn't include the exact ESP32-WROOM-32E module we'll use.
    Pins were kept the same as before, but will be rearenged before the
    schematics are final.
    [GameOverBase.kicad_sch]
2022-03-14 Moves battery sense pin to ADC1_CH0 (the SENSOR_VP pin)
    This is still in the ADC block 1, so it's not used by wifi, but is
    placed better in the module.
    [GameOverBase.kicad_sch]
2022-03-14 Moves ID latch/clock/data pins
    This means some of the IO that are broken out to the add-on changed, but
    not only are new new pins (GPIO/14,12,13) better placed on the module,
    but they also are block2 of the ADC, which means they can't be used for
    analog readings while wifi is used. If we're going to use a block of
    pins for digital IO, might as well use these.
    [GameOverBase.kicad_sch]
2022-03-14 Rearanges IO pins on connector
    The final position on the connector will probably change during the
    layout to make it easier to route signals, but the pins on the connector
    should be the ones connected now.
    [GameOverBase.kicad_sch]
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2022-03-14 Adds 100nF capacitor to the battery sensing pin
    As per recommended in the ESP32 hardware design guidelines[1], section
    2.6.
    Noise can be further reduced by using multisampling[2].
    [1]: https://www.espressif.com/sites/default/files/documentation/esp32_hardware_design_guidelines_en.pdf
    [2]: https://docs.espressif.com/projects/esp-idf/en/latest/esp32/api-reference/peripherals/adc.html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
    [GameOverBase.kicad_sch]
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2022-03-14 Associates some footprints to schematics symbols
    This adds capacitors, resistors, and other generic component footprints.
    The more specific ones will be associated later.
    [GameOverBase.kicad_sch]
2022-03-14 Adds footprint for PTC fuses
    We're using the Belfuse 0ZCJ fuses, but we need to make sure we buy one
    with the same footprint (or change it later).
    [GameOverBase.kicad_sch]
2022-03-14 Adds footprint for USB-C (power only) connector
    We're using the DEALON USB-US31-106.
    [GameOverBase.kicad_sch]
2022-03-14 Changes RGB led for battery indication to common anode
    This is the kind of LED we bought
    [GameOverBase.kicad_sch]
2022-03-14 Switches pins on RGB led based on the actual part we bought
    We'll be using the Hongzhi Forest HS-1204-RGB
    [GameOverBase.kicad_sch]
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2022-03-24 Fixes label on boot button
    [GameOverBase.kicad_sch]
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2022-03-24 Fixes footprint association for both tactile switches
    [GameOverBase.kicad_sch]
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2022-03-24 Fixes footprint for 4021B
    It actually uses TSSOP16 without thermal pads
    [GameOverBase.kicad_sch]
2022-03-25 Adds solder jumpers to the TX/RX lines
    This will make it easier to bodge the PCB in case we mix the lines up.
    [GameOverBase.kicad_sch]
2022-03-28 Adds two mouting holes for mechanically mounting the PCB onto the case
    I used M3 screws because they are much easier to find, but if this
    proves too big for the PCB, we can change them to M2.
    [GameOverBase.kicad_sch]
2022-03-28 Assigns footprints that were missing for the solder jumpers in TX/RX lines
    These were added in c98b2485 but I forgot to assign a footprint to them.
    [GameOverBase.kicad_sch]
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2022-04-02 Uses the MCU to check the battery charging status
    The STAT pin on the MCP73831 is low when the battery is charging,
    high when it's done and hiigh Z when shutdown or the battery is not
    present. This means we can read this pin from the microcontroller to
    know if the battery is being charged and indicate that using the RGB Led
    already present for battery level indication. The pull-up is necessary
    since when the charger or battery are not present the pin would be
    floating.
    We used GPIO39 on the esp32 for this reading, which means this pin is no
    longer broken out to the add-on boards. The connector changed to
    accomodate for that.
    [GameOverBase.kicad_sch]
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2022-04-03 Includes missing components in the power block
    I missed the battery connector, the fuse and the battery sensing voltage
    divider.
    [GameOverBase.kicad_pcb]
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2022-04-04 Groups ESP32 circuitry and add-on connector
    To do this, I reorganized the order the GPIO pins are broken out to the
    add-on connector.
    This is still missing the decoupling capacitors on the connector
    [GameOverBase.kicad_pcb, GameOverBase.kicad_sch]
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2022-04-04 Brings in resistors for the ESP_BOOT and ESP_EN lines that were missing
    [GameOverBase.kicad_pcb]
2022-04-04 Brings in DIP switches
    To route this I needed to swap around the pins on the latch and clock
    lines for the 4021 and also the RGB led.
    [GameOverBase.kicad_pcb, GameOverBase.kicad_sch]
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2022-04-04 Routes some missing GND pins
    [GameOverBase.kicad_pcb]
2022-04-04 Flips buttons to the back side of the board
    This side will be highest already because of the DIP switches. It makes
    sense to make an effort for all the tall components to be on the same
    side of the board.
    [GameOverBase.kicad_pcb]
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2022-04-07 Routes Power section
    This doesn't look like an ideal layout for it, but I had to put the
    battery connector on the other side of the PCB because of it's high
    profile and for lack of space.
    [GameOverBase.kicad_pcb]
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2022-04-07 Fixes ERC issues in schematics
    [GameOverBase.kicad_sch]
2022-04-07 Removes RX/TX jumpers from schematics
    They take up too much space
    [GameOverBase.kicad_sch]
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2022-04-08 Adds missing GND connection the te battery sense decoupling cap
    [GameOverBase.kicad_pcb]
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2022-04-08 Adds missing connection to battery status pull-up resistor
    [GameOverBase.kicad_pcb]
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2022-04-08 Fixes DRC errors around add-on connector
    [GameOverBase.kicad_pcb]
2022-04-08 Fixes all DRC errors
    This includes removing the 3D models I included for reference. I don't
    want to include them in the actual symbols because they are the wrong
    model.
    [GameOverBase.kicad_pcb]
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2022-04-08 Reduces bulk capacitance on usb connector VBUS
    10uF is too much, and could cause an inrush current too big for usb
    specs.
    [GameOverBase.kicad_pcb, GameOverBase.kicad_sch]
2022-04-11 Brings tag-connect further away from PCB edge
    It's still pretty close to the edge so it's mechanically not very
    stable. Ideally it would be closer to a mounting hole for added
    mechanical stability, but I couldn't find a good way of doing that on
    the PCB.
    [GameOverBase.kicad_pcb]
2022-04-11 Fixes silkscreen layer on DIP switch footprint
    [GameOverBase.kicad_pcb]
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2022-04-15 Fixes directory for BreakoutBoard
    [BreakoutBoard.kicad_pcb, BreakoutBoard.kicad_sch]
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2022-04-15 Removes mouting holes from breakout board
    This will be on a breadboard. It doesn't need mouting holes
    [BreakoutBoard.kicad_sch]
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2022-04-15 Fixes DRC warnings
    [BreakoutBoard.kicad_pcb]
2022-04-15 Adds labels to broken out pins
    [BreakoutBoard.kicad_pcb]
2022-04-15 Fixes position of the power connectors on breakout board
    [BreakoutBoard.kicad_pcb]
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2022-04-15 Removes jumper from sensor Vin pin
    I tested using the Vin pin and it worked as expected. Having the jumper
    there would probably make power delivery much worse. Also, it's easy
    enough to bodge this if we get it wrong since it will be sitting on pin
    headers.
    [BNO055Sensor.kicad_sch]
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2022-04-15 Routes BNO055 breakout board
    The SDA/SCL pins shouldn't be swapped as we're using the hardware i2c
    which are in set pins on the esp32 (18/19).
    [BNO055Sensor.kicad_pcb]
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2022-04-15 Fixes DRC errors on sensor board
    [BNO055Sensor.kicad_pcb]
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2022-04-17 Translate layer names
    It turns out Kicad creates layers with translated names and JLCPCB's
    order page doesn't deal well with non-standard gerber file naming.
    [AddonTemplate.kicad_pcb, BNO055Sensor.kicad_pcb, BaseBoard.kicad_pcb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]
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2022-05-04 Decreases opening for the FFC cable
    It doesn't need to be this big, since the cable will is actually
    narrower than the connector.
    [BaseBoard.kicad_pcb]
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2022-05-04 Moves the tag-connect connector a bit more
    This should improve the mechanical stability, as it's a little less
    further into the PCB.
    [BaseBoard.kicad_pcb]
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2022-05-16 Fixes RGB led symbol
    The Hongzhi Forest HS-1204-RGB is actually a BGAR led. Pin 1 is blue, 2
    is green, 3 is the anode and 4 is red. The old symbol had red and the
    anode swapped, which means the LED doesn't work correctly in rev 0.1 of
    the board.
    [BaseBoard.kicad_sch]
2022-05-16 Changes version of the schematics to 0.2
    We're fixing some mistakes, but also adding new functionality, so this
    is still not 1.0 version.
    [BaseBoard.kicad_sch]
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2022-05-16 Adds GameOver logo as a symbol in the schematics
    This will make sure the logo doesn't get deleted when we update the
    board form the schematics.
    [BaseBoard.kicad_sch]
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2022-05-16 Reroutes pins for the LED
    After fixing the schematic symbol, we needed to reflect the changes in
    the layout.
    [BaseBoard.kicad_pcb, BaseBoard.kicad_sch]
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2022-05-16 Creates separate footprint for add-on and base connector
    They now have marks where they need to connect together which makes it
    easier on the user since they are flipped relative to each other.
    I also add the 3D model for another connector. It's not correct, but I
    changed my mind again about having them.
    [BaseBoard.kicad_pcb, BaseBoard.kicad_sch]
2022-05-16 Fixes swapped pins on addon connector symbol
2022-05-16 Fixes footprint in the addon connector symbol
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2022-05-26 Fixes orientation for sensor board
    The idea is to use the base board with the ESP32 facing down, and the
    sensorboard with the sensor facing up. That way the connectors will face
    each other correctly and the sensor will have space above (it wouldn't
    fit between the boards because the battery will already be there).
    [BNO055Sensor.kicad_pcb]
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2022-05-27 Swaps switch and led pins for top row
    This will make it easier to route the top buttons.
    [Keypad.kicad_pcb, Keypad.kicad_sch]
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2022-05-27 Flips buttons on keypad
    The keypad will have the same orientation as the Sensor board (with the
    FFC connector on top). The buttons will be on the same side as the
    connector.
    [Keypad.kicad_pcb, Keypad.kicad_sch]
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2022-05-27 Fixes issue with battery status input
    The battery status will be pulled high by the MCP73831 to it's VDD (5V)
    when charging is done. This is higher than the 3.3V (+0.3V) allowed as
    input to the ESP32. By adding a voltage divider we bring this to a lower
    level with which we can interface to the ESP32.
    When no 5V or no battery is present, the pin will be floating, so this
    pin should have a internal pull-up to make sure we read the value
    correctly. An internal pull-up will mean we'll see a high value with any
    of charge complete, no 5V input, or no battery, which means a high value
    whenever not charging.
    The 150k resistor adds to the BOM, but in conjunction with the 100k it
    will bring the 5V d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
    [BaseBoard.kicad_pcb, BaseBoard.kicad_sch]
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2022-05-27 Fixes logo reference so it's included in the BaseBoard.
    [BaseBoard.kicad_pcb, BaseBoard.kicad_sch]
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2022-05-27 Fixes logo reference in keypad schematics
    [Keypad.kicad_pcb, Keypad.kicad_sch]
2022-05-27 Fixes logo schematics in the Addon template
    [AddonTemplate.kicad_sch]
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2022-05-28 Replaces MBR120 in power latch circuit for a BAS20
    This is much cheaper and should be enough for this part of the circuit.
    [BaseBoard.kicad_sch]
2022-05-28 Renames new power symbol to battery_switched
    This also fixes the pin assignement inside the symbol.
    [BaseBoard.kicad_sch]
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2022-05-30 Fixes isolated copper fill warning
    [BaseBoard.kicad_pcb]
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2022-08-21 Uses fixed LED to indicate charging status instead of the uC
    We're now using a single led to indicate if the battery is currently
    being charged. It will turn off as soon as the battery is fully charged.
    [BaseBoard.kicad_sch]
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2022-08-21 Fixes pin order in the add-connector symbol
    GPIOs 5 and 18 had the order wrong in the add-on connector. This fixes
    the symbol but still doesn't update the other schematics/layouts.
2022-08-21 Updates all add-on boards with fix introduced in 692041
    [AddonTemplate.kicad_pcb, AddonTemplate.kicad_sch, BNO055Sensor.kicad_pcb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]
2022-08-21 Rotates the battery connector 90 degrees
    This will make it easier to plug and unplug the battery and to fit the
    entire system in a tight enclosure.
    [BaseBoard.kicad_pcb]
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2022-08-24 Adds box to hold the hardware during performances
    This was designed out of this repo, so there are no step by step
    commits, sorry.
    The main idea is that the base board sits on the stands (the ones with
    holes should be fitted with heat-set inserts to accept M2 spacers) with
    the ESP32 facing down, the add-on sits on top of stands that separate
    the two PCBs, and the battery in between (ideally with some foam to hold
    it in place and avoid damage). In my preliminary tests, the battery
    between the boards did not significantly reduce the antenna's
    performance. The big gap on the right is to accommodate the FFC cables,
    which we couldn't find in smaller size.
    Different lids should be designed for e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
    [box.scad]
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2022-08-27 Adds logo to the side of the box
    This prints much better since it doesn't need support.
    [box.scad]

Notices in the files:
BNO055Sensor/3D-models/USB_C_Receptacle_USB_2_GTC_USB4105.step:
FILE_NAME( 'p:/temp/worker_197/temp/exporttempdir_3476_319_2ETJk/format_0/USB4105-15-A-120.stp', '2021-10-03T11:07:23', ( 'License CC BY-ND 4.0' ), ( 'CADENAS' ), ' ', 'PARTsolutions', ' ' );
